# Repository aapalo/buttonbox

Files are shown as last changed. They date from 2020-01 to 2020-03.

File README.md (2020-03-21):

# Button box

The TM Cougar Throttle USB-mod has been forked into its own repository, which can be found from here: 
<https://github.com/aapalo/cougar-usb>

Features:
- Can be used to convert a TM Cougar Throttle into a USB device, or as a stand-alone button box.
- Several boards can be daisy-chained via the 1x5 pin socket J11.
- The dimensions of the PCB are 112mm * 37mm.

v1.0 errata:
- Pro micro pin 9, PM_C7, should be PM_D7

----

The required components include:
- Arduino board, Pro Micro 5V/16MHz ATmega32U4
- Shift register, 74HC165N, DIP-16
- SMD resistors, 10k Ohm, 0805
- SMD capacitors, 470nF, 0805
- Pin sockets and/or headers, 2.54mm pitch
- Buttons/switches
- Jumper wires for the buttons/switches

----

The recommended software to program the Pro Micro is MMJoy2:
<https://simhq.com/forum/ubbthreads.php/topics/3899105/mmjoy-mmjoy2-build-your-own-usb-controller>

When used as a stand-alone button box, the board should fit inside a Hammond [1591C*](1) or a [1591XXC](2) enclosure.

[1]: <http://www.hammondmfg.com/dwg2.htm>
[2]: <https://www.hammfg.com/part/1591XXCBK>
[3]: <http://www.hammondmfg.com/dwg2XX.htm>

----

[//]: # (Todo: add pictures of a soldered version)

A soldered and installed version in use:
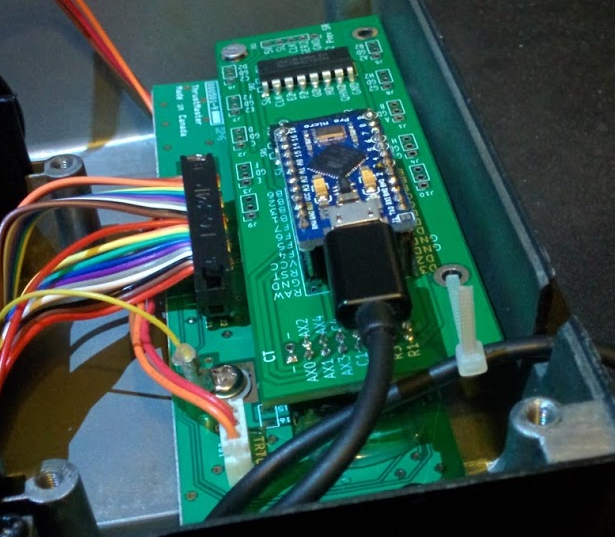
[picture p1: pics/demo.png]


The schematic, with some of the planned DCS key bindings visible:
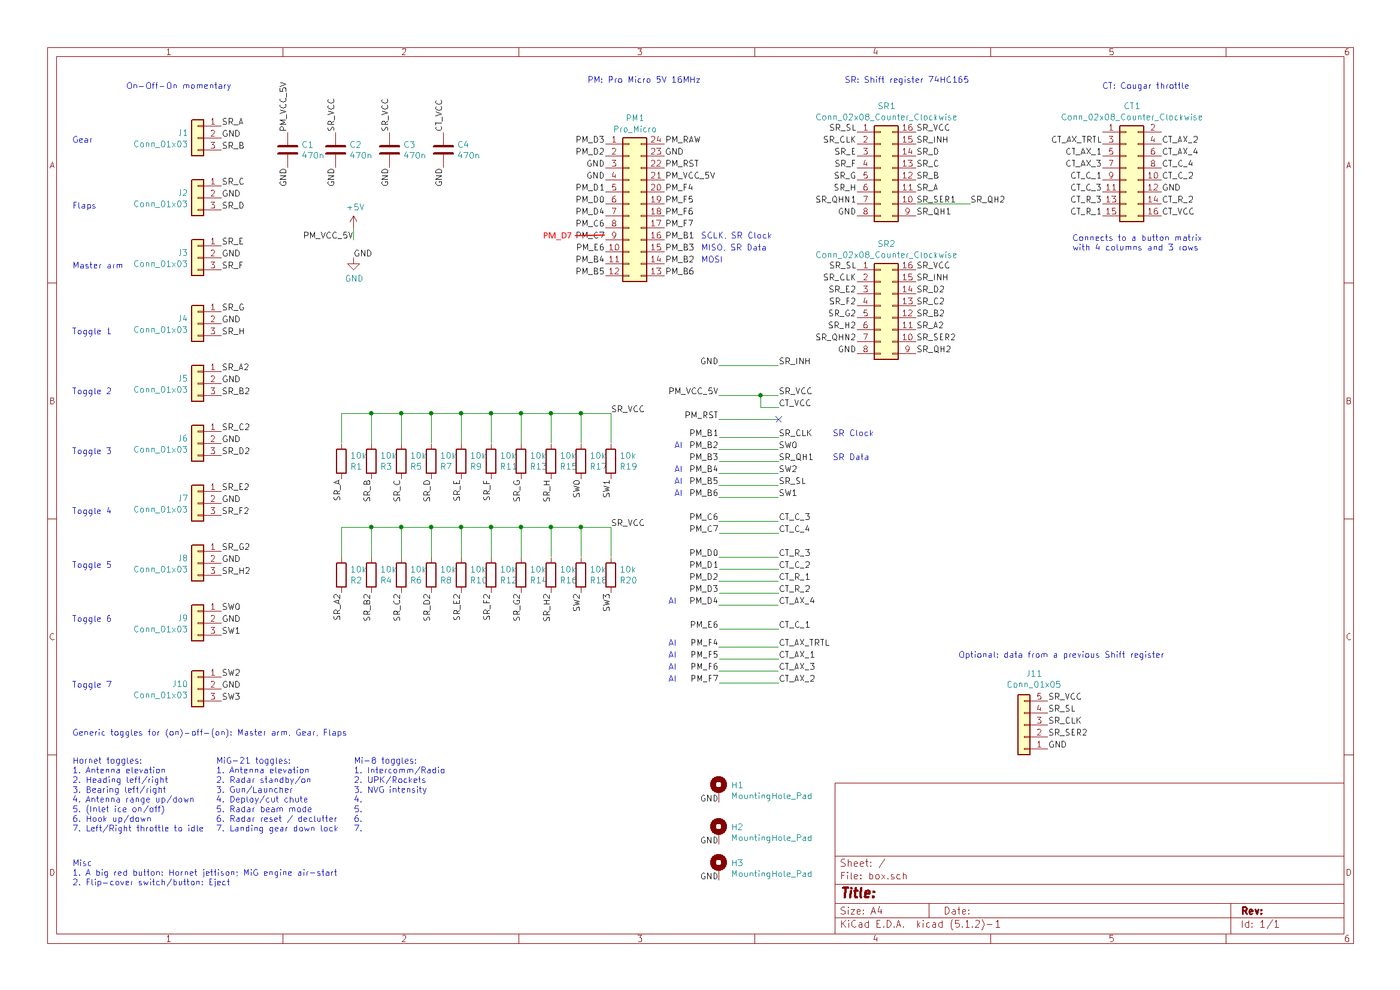
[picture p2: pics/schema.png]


Top side, with the 3d view and layout view:
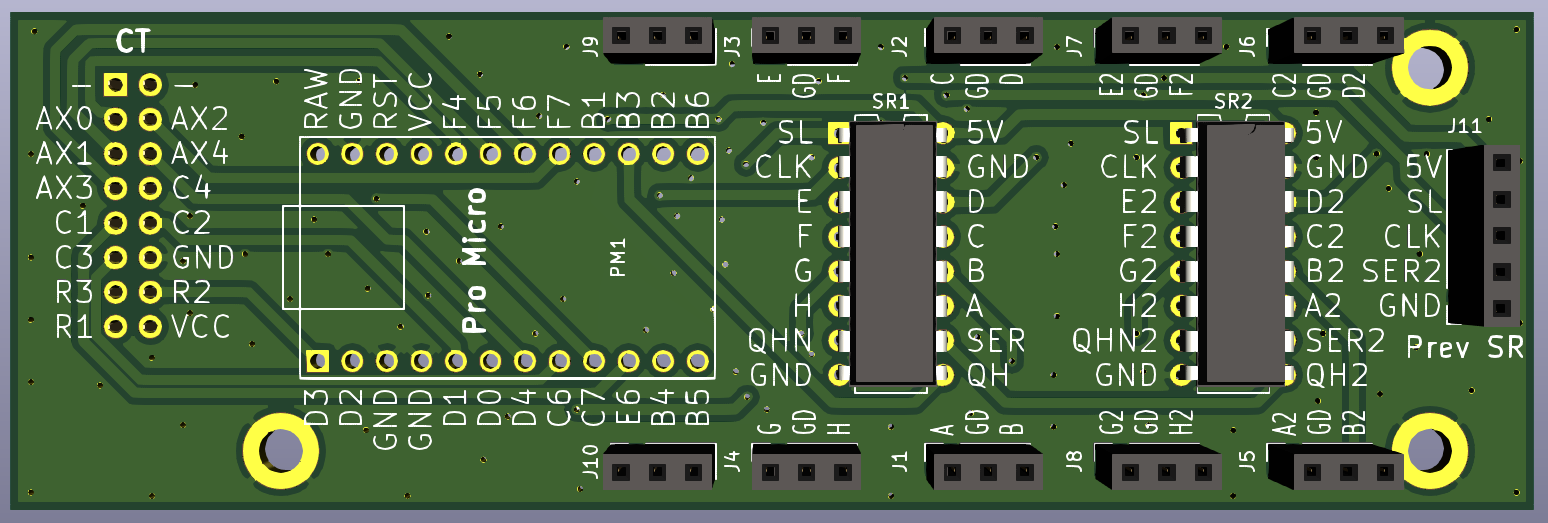
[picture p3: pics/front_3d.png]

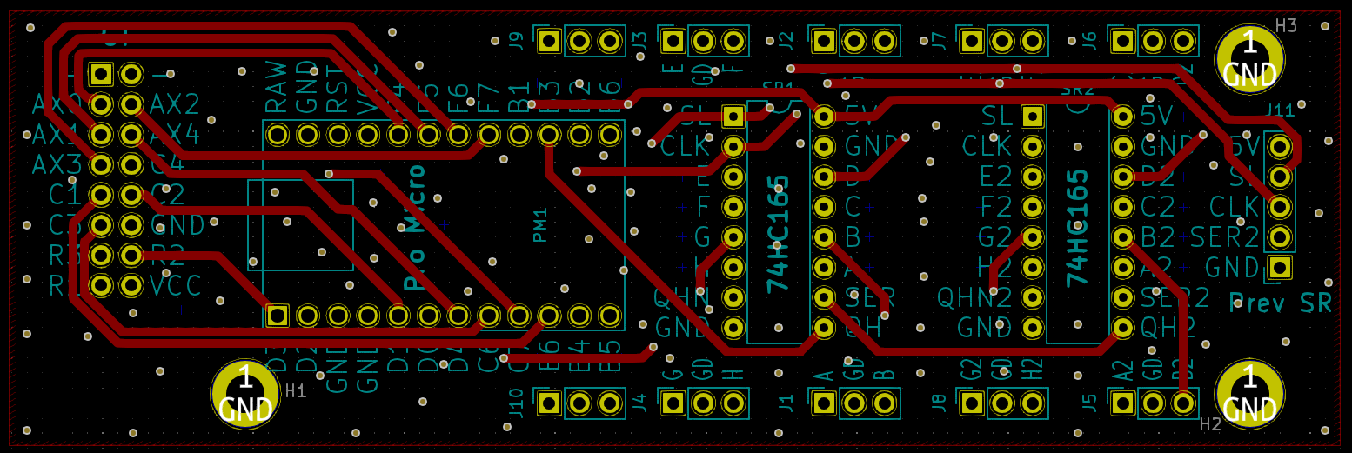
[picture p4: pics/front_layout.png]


Bottom side, with the 3d view and layout view:
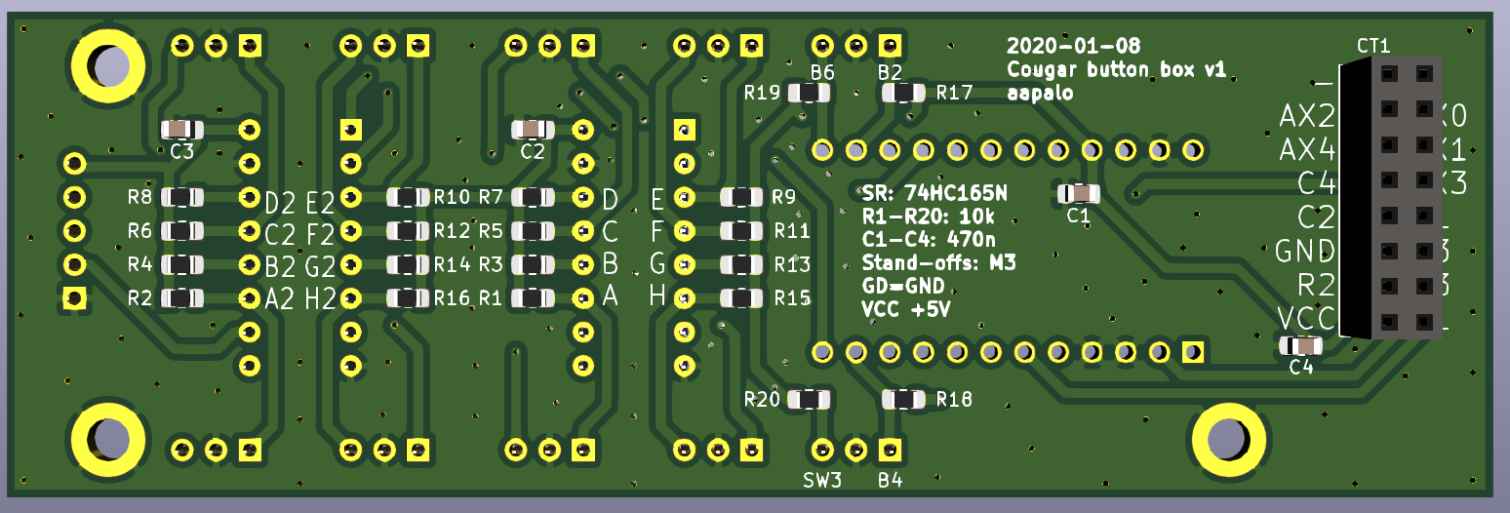
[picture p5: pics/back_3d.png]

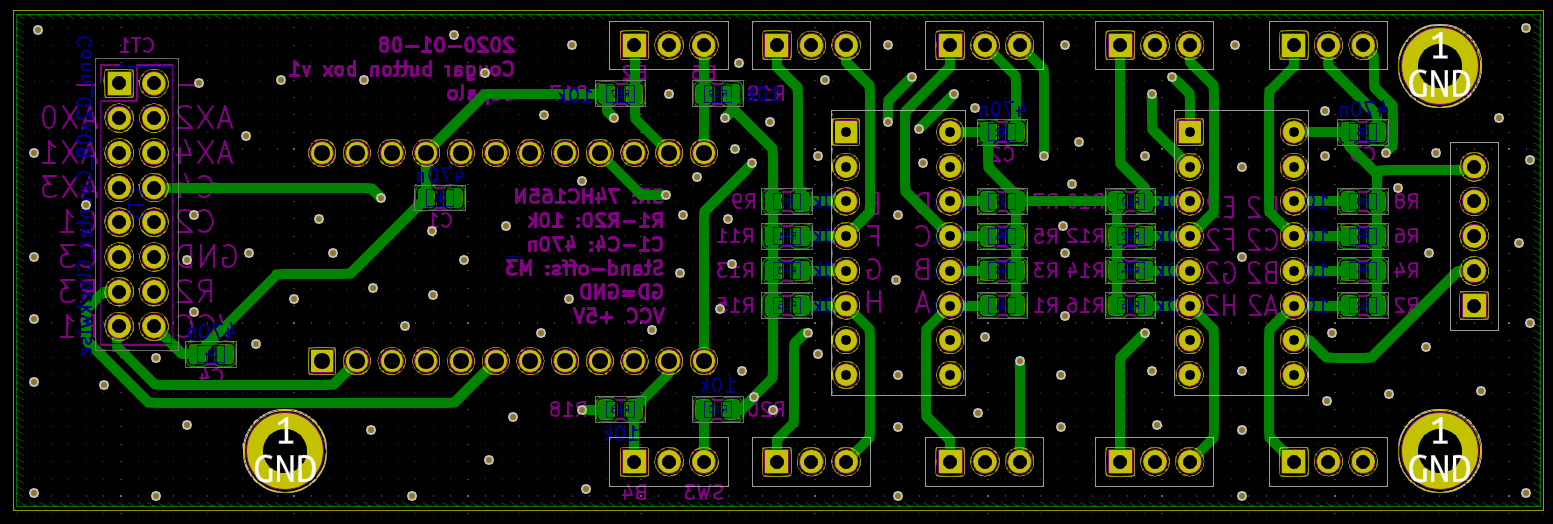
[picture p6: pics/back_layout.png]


Both the top and bottom layer visible:
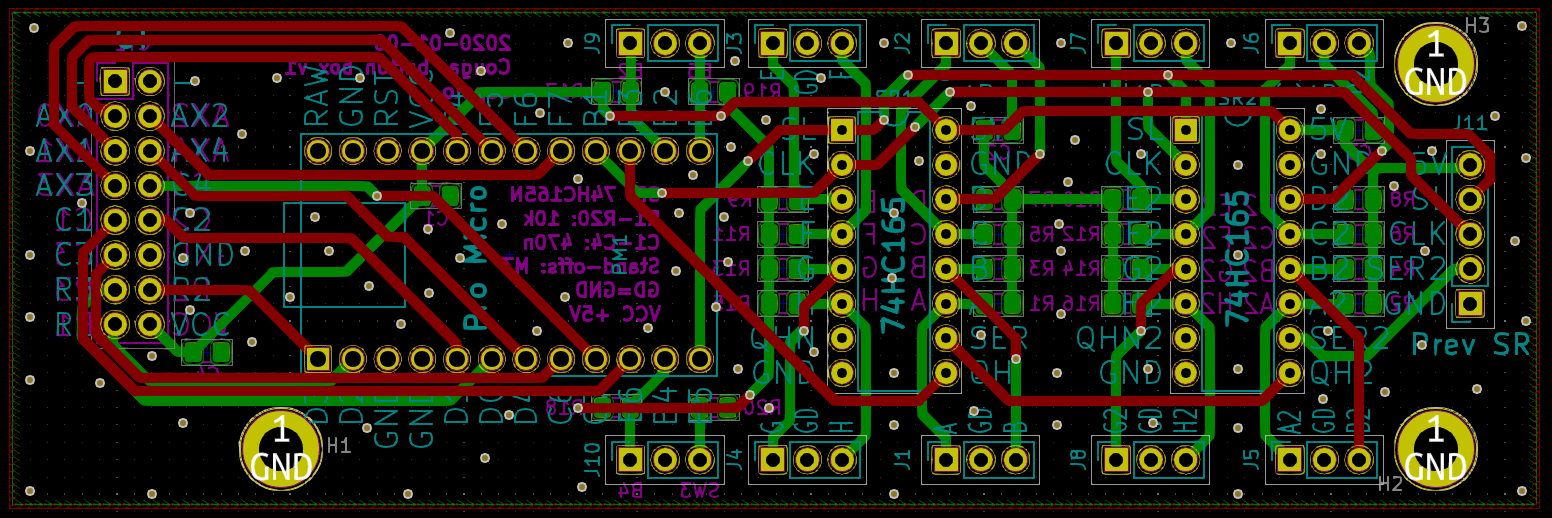
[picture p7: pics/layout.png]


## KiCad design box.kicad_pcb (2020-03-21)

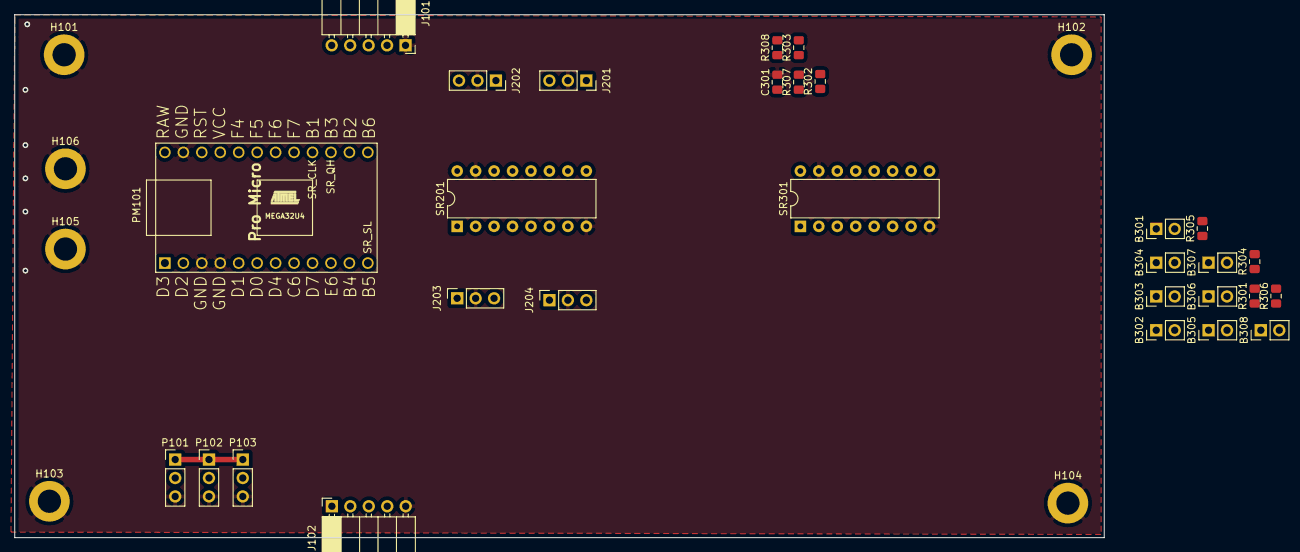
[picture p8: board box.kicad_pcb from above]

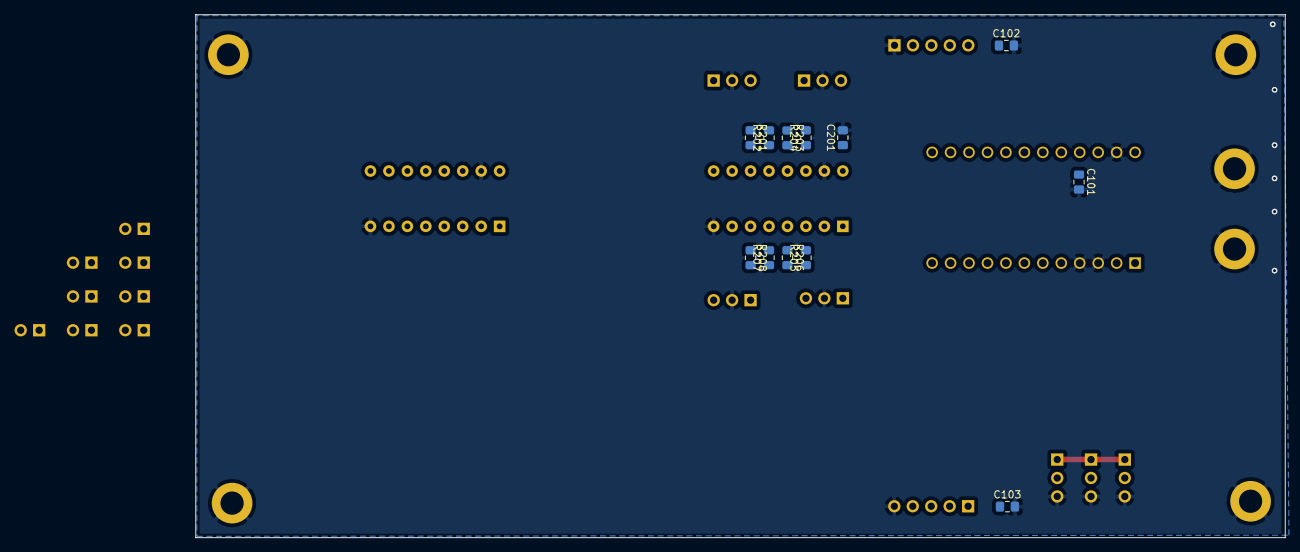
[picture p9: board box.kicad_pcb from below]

Board: 2 copper layers, 150.0 x 72.0 mm, 47 parts (12 on the bottom side), 23 nets.

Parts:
B301, B302, B303, B304, B305, B306, B307, B308: Conn_01x02; PinHeader_1x02_P2.54mm_Vertical
C101, C102, C103, C201, C301: 470n; C_0805_2012Metric_Pad1.15x1.40mm_HandSolder
H101, H102, H103, H104, H105, H106: MountingHole_Pad; MountingHole_3.2mm_M3_DIN965_Pad
J101, J102: Conn_01x05; PinSocket_1x05_P2.54mm_Horizontal
J201, J202, J203, J204: Conn_01x03; PinSocket_1x03_P2.54mm_Vertical
P101, P102, P103: Conn_01x03_Male; PinHeader_1x03_P2.54mm_Vertical
PM101: Pro_Micro; promicro
R201, R202, R203, R204, R205, R206, R207, R208, R301, R302, R303, R304, R305, R306, R307, R308: 10k; R_0805_2012Metric_Pad1.15x1.40mm_HandSolder
SR201, SR301: Conn_02x08_Counter_Clockwise; DIP-16_W7.62mm

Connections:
+5V: C101.1, C102.1, C103.1, C201.1, C301.1, J101.5, J102.1, P101.1, P102.1, P103.1, PM101.21, R201.1, R202.2, R203.1, R204.2, R205.1, R206.2, R207.1, R208.2, R301.1, R302.1, R303.1, R304.1, R305.1, R306.1, R307.1, R308.1, SR201.16, SR301.16
/CAT: B308.2, R308.2, SR301.6
/Eight buttons/SR_DATA_IN: SR201.10, SR301.9
/H1: B301.2, R301.2, SR301.11
/H2: B302.2, R302.2, SR301.12
/H3: B303.2, R303.2, SR301.13
/H4: B304.2, R304.2, SR301.14
/H5: B305.2, R305.2, SR301.3
/H6: B306.2, R306.2, SR301.4
/H7: B307.2, R307.2, SR301.5
/PM_B1: J101.3, J102.3, PM101.16, SR201.2, SR301.2
/PM_B3: J102.4, PM101.15, SR301.10
/PM_B5: J101.4, J102.2, PM101.12, SR201.1, SR301.1
/SR_SER2: J101.2, SR201.9
/flaps_dn: J203.3, R206.1, SR201.4
/flaps_up: J203.1, R205.2, SR201.3
/gear_dn: J202.3, R204.1, SR201.14
/gear_up: J202.1, R203.2, SR201.13
/hdg_left: J204.1, R207.2, SR201.5
/hdg_right: J204.3, R208.1, SR201.6
/hook_dn: J201.3, R202.1, SR201.12
/hook_up: J201.1, R201.2, SR201.11
GND: B301.1, B302.1, B303.1, B304.1, B305.1, B306.1, B307.1, B308.1, C101.2, C102.2, C103.2, C201.2, C301.2, H101.1, H102.1, H103.1, H104.1, H105.1, H106.1, J101.1, J102.5, J201.2, J202.2, J203.2, J204.2, P101.3, P102.3, P103.3, PM101.3, PM101.4, PM101.23, SR201.8, SR201.15, SR301.8, SR301.15

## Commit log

2020-01-13 Initial release
    [box.kicad_pcb, box.sch]
2020-03-21 Update March 21st
    [box.kicad_pcb, box.sch, buttons8.sch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]
